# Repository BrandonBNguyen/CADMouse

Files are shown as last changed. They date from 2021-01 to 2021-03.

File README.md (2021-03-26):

# CAD Mouse Project

## Introduction

I took on this project because the middle mouse button on my mouse doesn't work well and if you're familiar with Solidworks and many other CAD software, the middle mouse button is often used to rotate, pan, and roll the model you are viewing. Manipulating the view of a CAD model without a functioning middle mouse button can be quite frustrating so I took on the task of developing a separate controller I could use specifically for performing these functions.

project showcase

## Part Selection

### Sensor Selection

I initially started by thinking about what sensors I would want to use to interpret commands to rotate, pan, roll, and zoom the view model. 

For the actions of rotating and panning the view model, I selected a simple joystick controller I had leftover from an Arduino kit because rotating and panning are actions that require both horizontal and vertical inputs from the mouse.

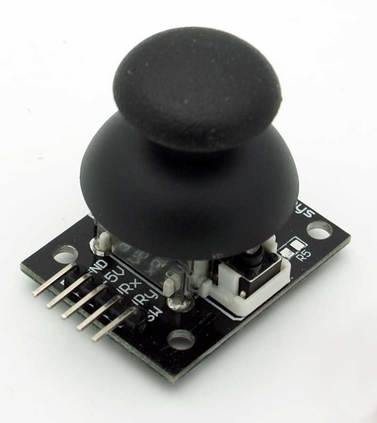
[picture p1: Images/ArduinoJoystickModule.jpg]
Arduino Joystick Module


For the actions of rolling and zooming the view model, I selected the KY-040 rotary encoder as these actions only require mouse movement along a single axis.

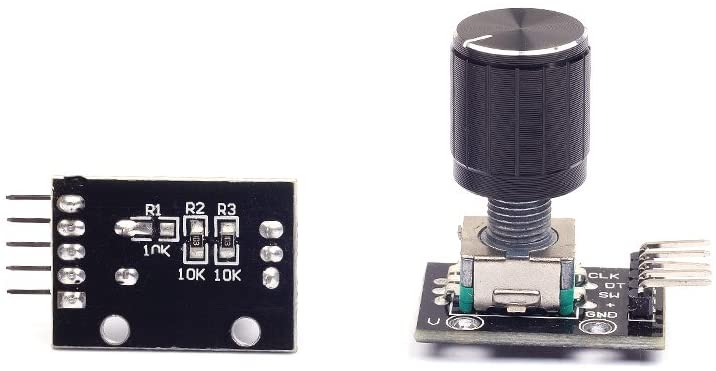
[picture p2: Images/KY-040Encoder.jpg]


### Board Selection

From preliminary testing with an Arduino Uno (which was unable to stimulate keyboard and mouse inputs to a computer), I knew I needed to select a microcontroller that would be able to appear as a native mouse and keyboard by implementing the `Mouse.h` and `Keyboard.h` libraries. As a result, I selected the Arduino Micro, which is a small Arduino board capable of implementing these libraries.

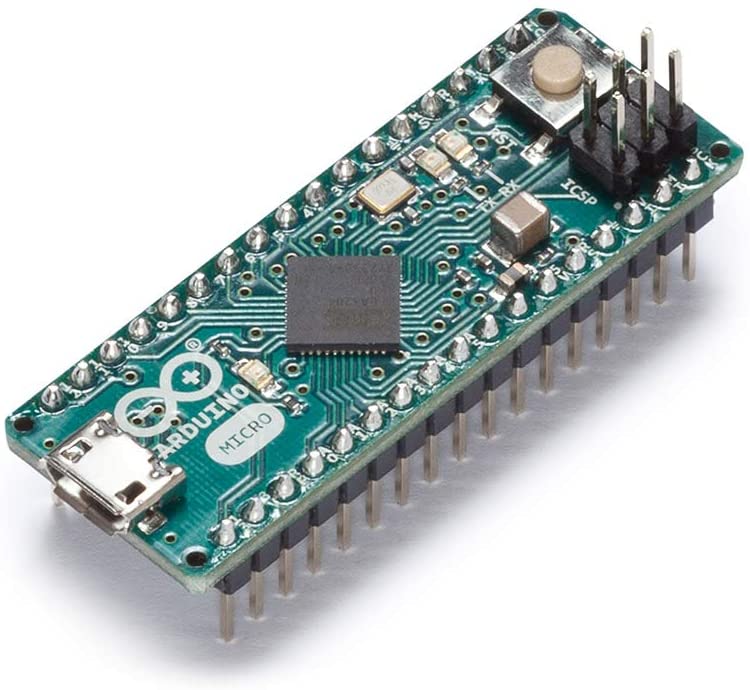
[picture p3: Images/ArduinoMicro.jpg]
Arduino Micro Microcontroller


## CAD Model

I started the design by importing existing CAD models of the electronic components into Solidworks and drawing  a rudimentary sketch of their placements relative to each other, being sure to take into account the clearances required of the Dupont wire connections to the sensor and board pins.

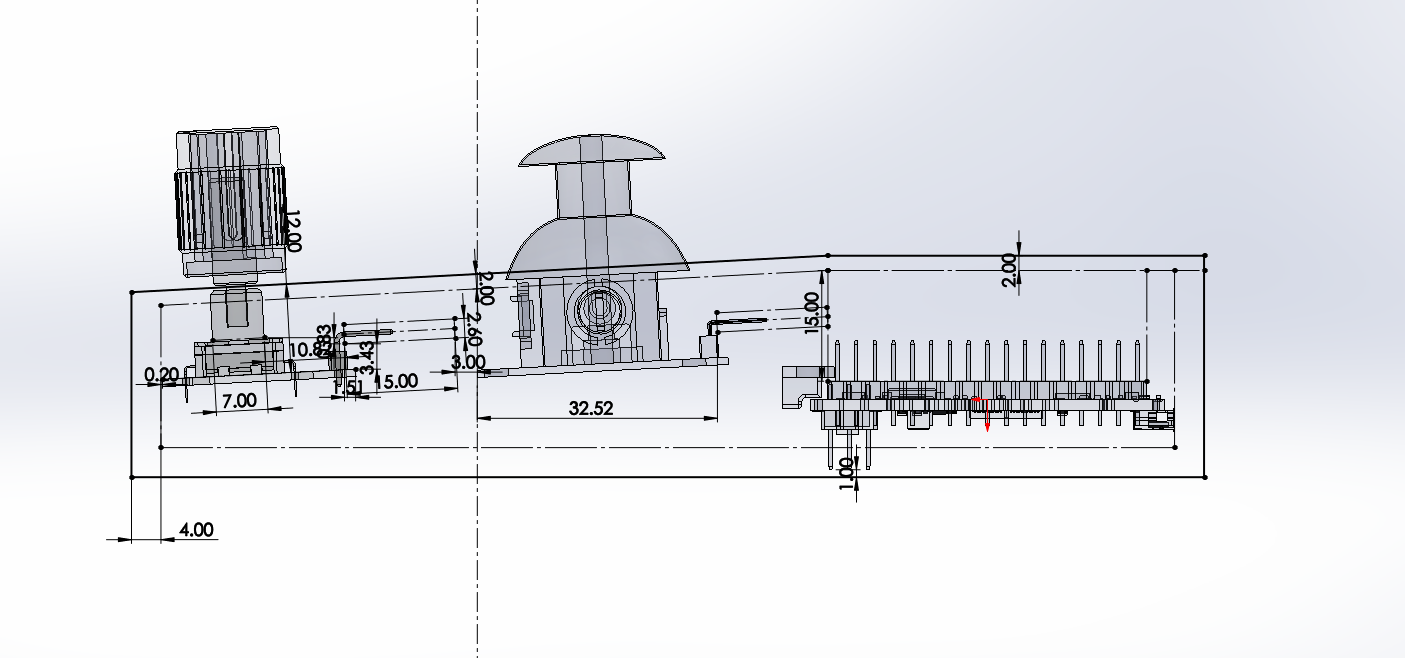
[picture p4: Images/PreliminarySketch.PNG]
Preliminary placement sketch


After fully defining and determining their placements, I modeled a case that would hold all the components in place via fasteners and provide an opening at the end for the micro USB port on the Arduino Micro. 

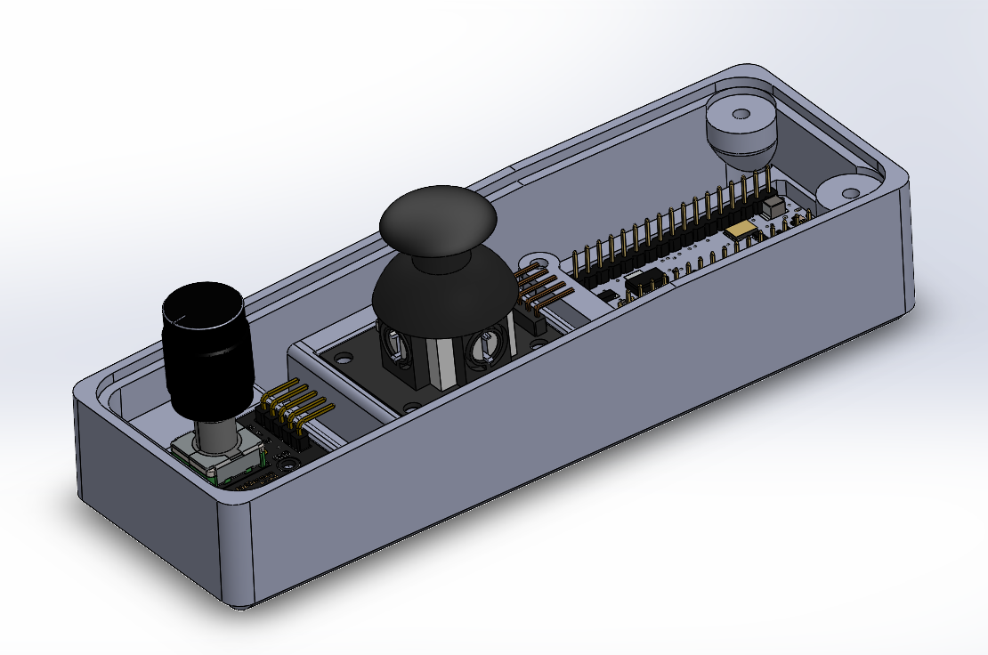
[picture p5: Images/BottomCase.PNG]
Case Model


After the case was designed, I modeled the lids that would be fastened to the case and enclose the wiring.

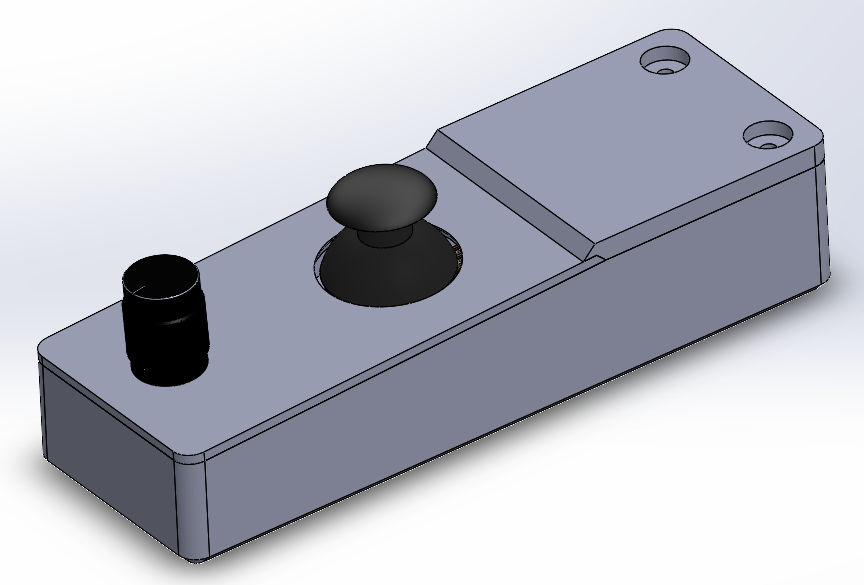
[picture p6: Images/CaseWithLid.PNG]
Enclosed Case Model


## Manufacturing

### 3D Printing

In order to prevent wasted plastic, I started by printing specifically the sections  of the case that interfaced with the electronic components to ensure proper fitting. By performing this step, I was able to find several instances where the components did not fit due to minor deviations between the CAD models of the components and their actual dimensions. Taking into account these differences, I was able to modify the CAD such that the components fit properly.

Below is a screenshot of the various iterations of the test prints used to ensure proper fitting of components to the case.

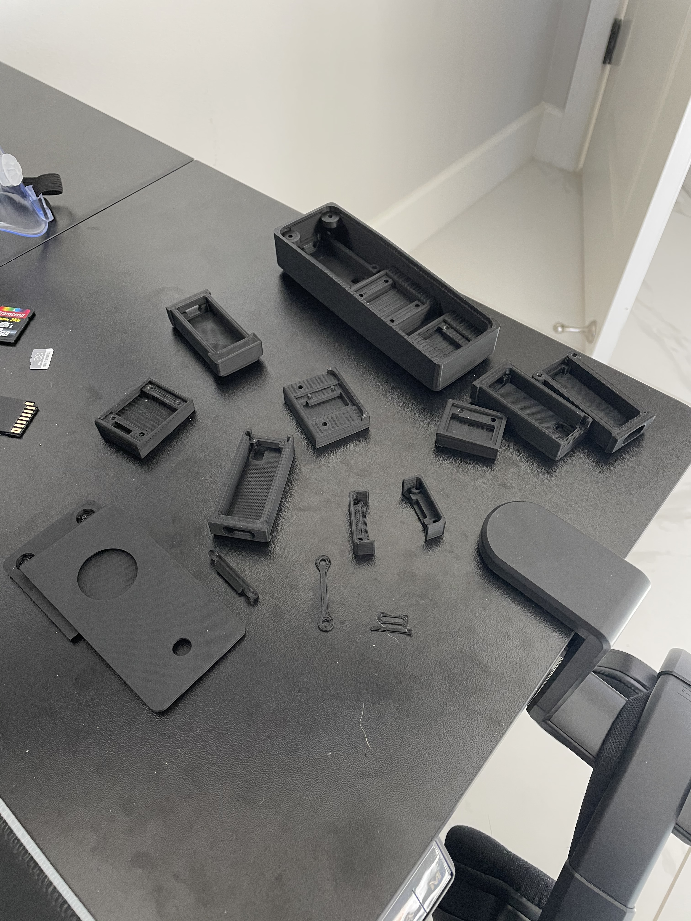
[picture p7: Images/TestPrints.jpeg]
Test Prints


### Wiring

The wiring between the sensors and the microcontroller was done using Dupont connectors. The connectors between the joystick and the Arduino Micro were shortened by cutting out segments of the connector, stripping the ends, soldering them together, and insulating them with electrical tape. 

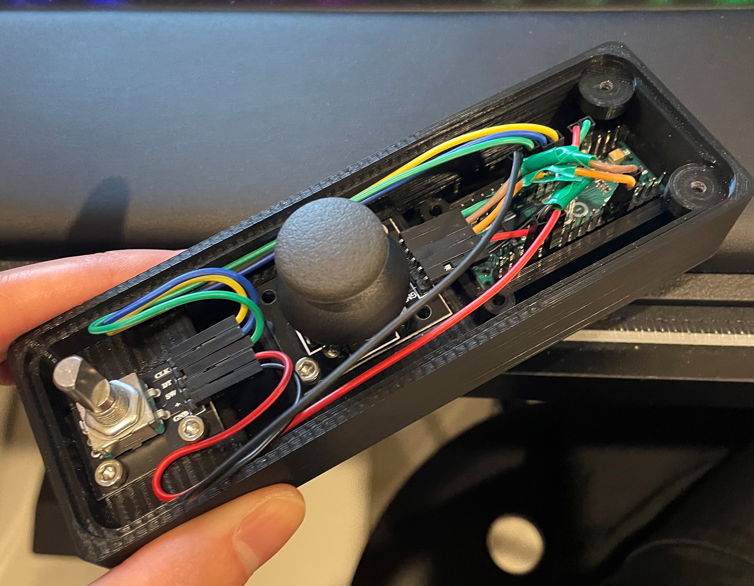
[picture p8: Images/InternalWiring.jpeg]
Internal Wiring


## User Guide

When the mouse is intially connected and booted up, the joystick controller is set such that moving it will cause the model to be rotated and the knob controller is set such that rotating it will cause the model to be rolled. 

Pressing down on the joystick and activating its switch will cause it to enter a panning mode such that inputs from the joystick cause the model to be panned instead of rotated. Pressing the joystick again will put it back in rotating mode.

Pressing down on the knob and activating its switch will cause it to enter a zooming mode such that inputs from the knob will cause the view window to zoom in and out of the model. Pressing the knob again will return the knob to rolling mode.

## Code Implementation

### Technical Challenges

The code run by the CAD Mouse is written and organized in `CAD_Mouse.ino`. The major technical problem I encountered while getting the mouse to manipulate the model smoothly was the mouse cursor colliding with the edge of the screen, preventing the view model from continuing to be moved in any way. The solution I came up with for this problem was to have the controller record the movements of the mouse from its initial position when the mouse was being used. During use, if the mouse cursor strayed too far from its initial position, the cursor would be quickly moved back to its initial position before continuing. This allowed the rotating and panning of view model to be fairly smooth when moving continuously.

### Organization

#### setup()

The initial `setup()` function is used to set up the input pins to read from the sensors and record the initial position of the rotary encoder.

#### loop()

The main `loop()`function reads data from the sensors and stimulates mouse and keyboard inputs to manipulate the CAD view. It performs the following tasks in sequence.

 1. Read the position of the joystick.
 2. Determine if the joystick switch has been pressed and switch between rotating and panning mode, accordingly.
 3. Determine if the knob switch has been pressed and switch between rolling and zooming mode, accordingly.
 4. If the joystick leaves the center position, begin stimulating mouse and keyboard inputs to move the CAD view model. If the joystick was already outside the center position, continue stimulating mouse movements to move the model. If the joystick reenters the center position, stop stimulating mouse and keyboard inputs.
 5. If the joystick isn't being used, read input from the rotary encoder. If the rotary encoder starts moving, begin stimulating mouse and keyboard inputs to move the model. Continue moving the model while rotary encoder  is still recording movement. If the rotary encoder has not recorded movement for a specified time, stop stimulating mouse and keyboard inputs.

Additionally, the code is factored in to several functions to help facilitate the tasks carried out by `loop()` and prevent repetitive code.

## Attributes

The links to the pre-made models used in the CAD made for this project are linked below.

 - [Arduino Micro](https://grabcad.com/library/arduino-micro-1) by Andrew Whitham
 - [HW-504 Joystick Module](https://grabcad.com/library/keyes-joystick-hw-504-1) by Barış Baylav
 - [KY-040 Rotary Encoder](https://grabcad.com/library/ky-040-rotary-encoder-1) by ∏-∑-A

## Skills Demonstrated

 - Demonstrated knowledge of C++ and applied it to use a microcontroller to read sensor data and control a system based on sensor inputs.
 - Demonstrated ability to write organized, well-commented code and write project documentation.
 - Demonstrated strong computer-aided design skills and good workflow by constraining existing components and developing custom parts around those in an assembly.
 - Demonstrated ability to perform rapid prototyping with the use of FDM 3D printing to test component fitting.

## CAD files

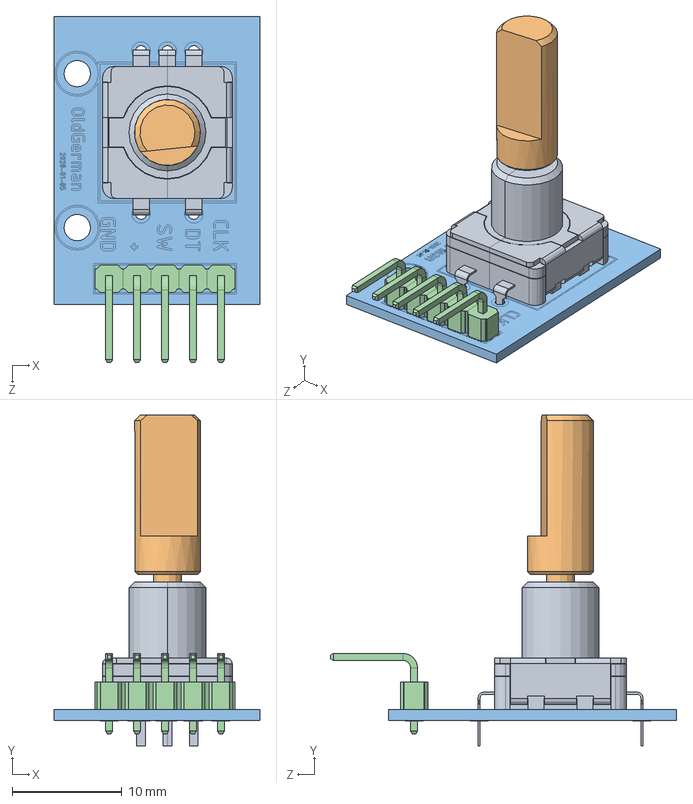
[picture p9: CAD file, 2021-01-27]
CAD/KY-040 Encoder/KY-040 Rotary Encoder.SLDASM
18.7 x 30.1 x 31.5 mm
Rotary Encoder
D-handle
pcb
2.54 5PIN 90

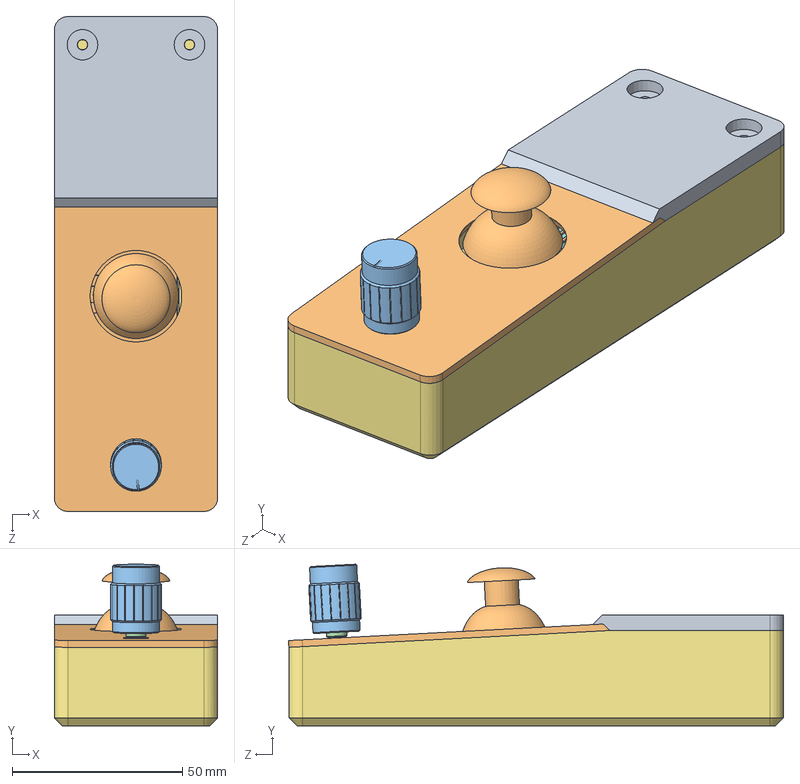
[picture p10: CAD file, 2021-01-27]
CAD/00 CAD Mouse.SLDASM
48.0 x 47.5 x 145.4 mm
arduinoMicro
Joystick HW504 Board
Rotary Encoder
D-handle
pcb
2.54 5PIN 90
Case Bottom
Arduino Micro Lid^CAD Mouse
Top Panel^CAD Mouse
Front Panel^CAD Mouse
Knob

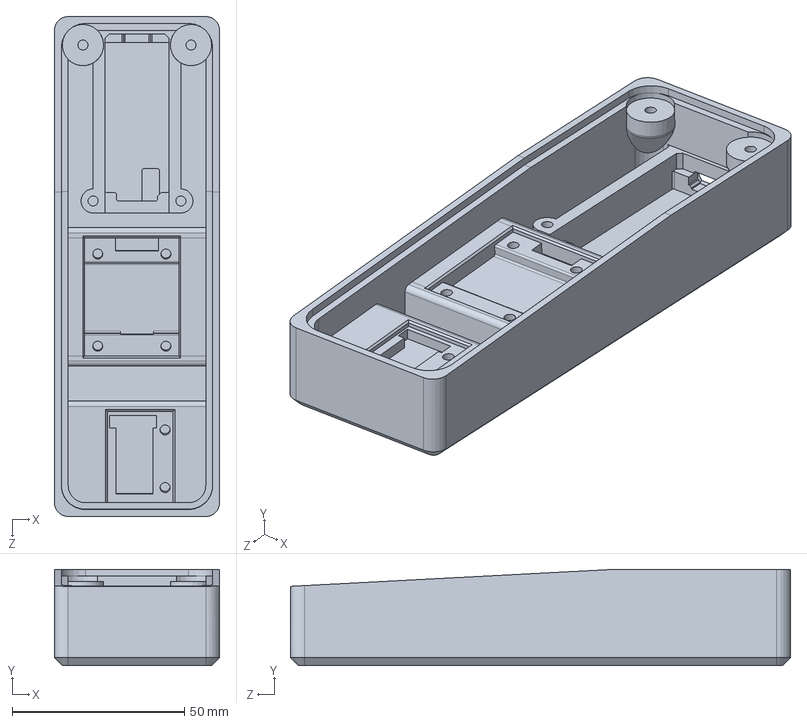
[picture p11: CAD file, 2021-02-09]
CAD/Case Bottom.SLDPRT
48.0 x 28.0 x 145.3 mm

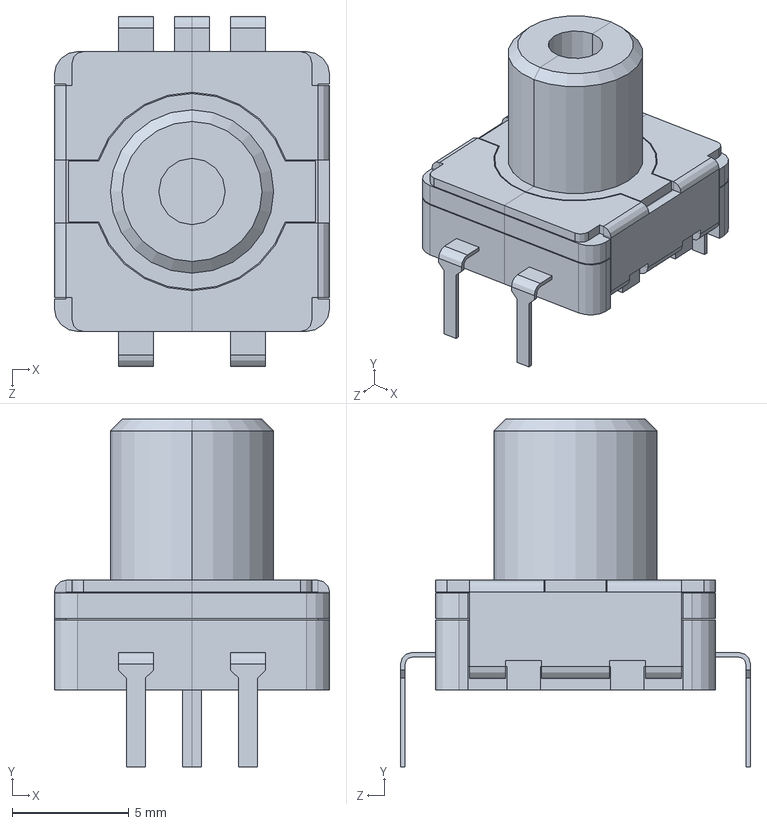
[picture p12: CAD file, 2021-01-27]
CAD/KY-040 Encoder/Rotary Encoder.SLDPRT
11.8 x 14.9 x 15.0 mm

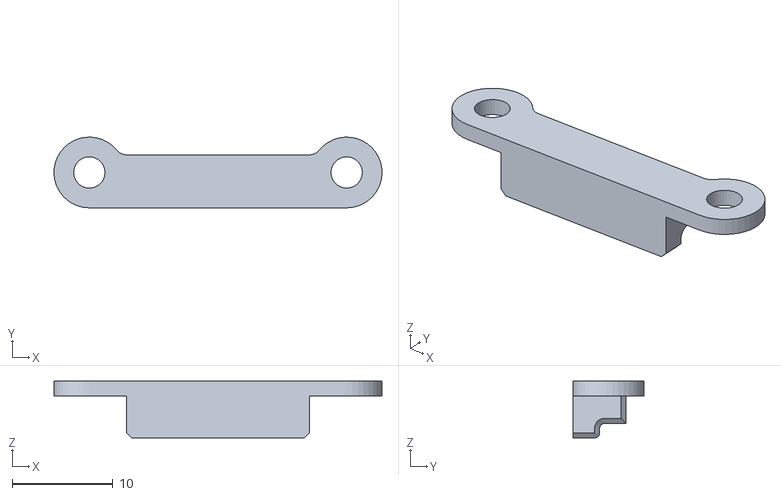
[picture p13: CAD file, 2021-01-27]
Print STL Files/Arduino Micro Lid.STL
32.5 x 7.02 x 5.65

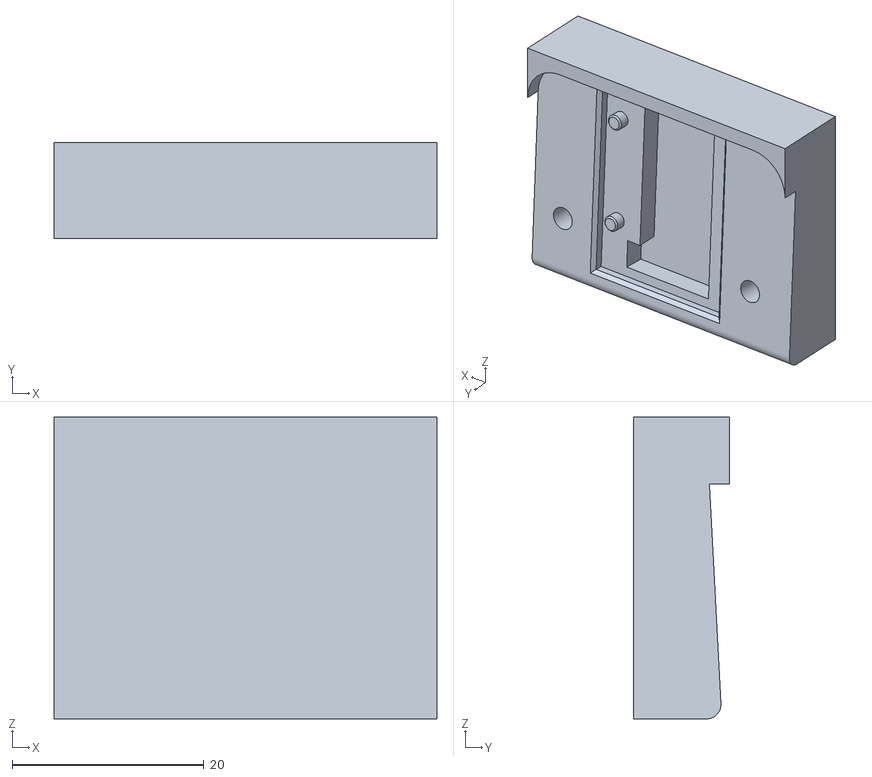
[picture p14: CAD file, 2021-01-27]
Test Prints/Rotary Encoder Holder (Holed).STL
40.0 x 10.0 x 31.5

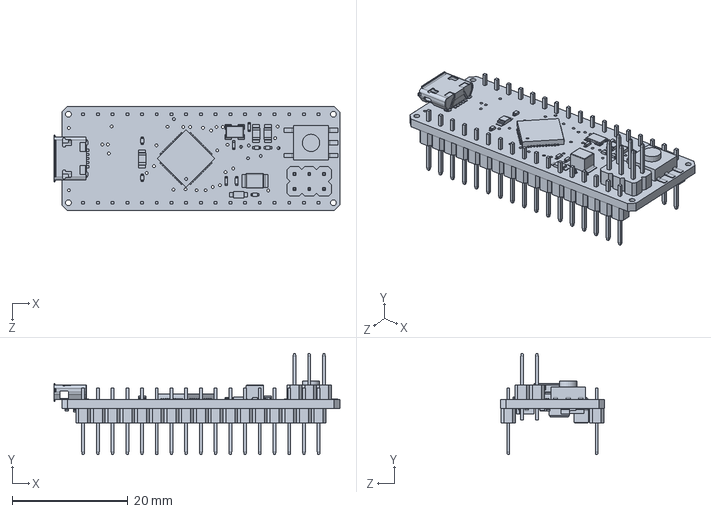
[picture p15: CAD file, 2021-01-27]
CAD/arduinoMicro.SLDPRT
49.4 x 17.5 x 18.0 mm

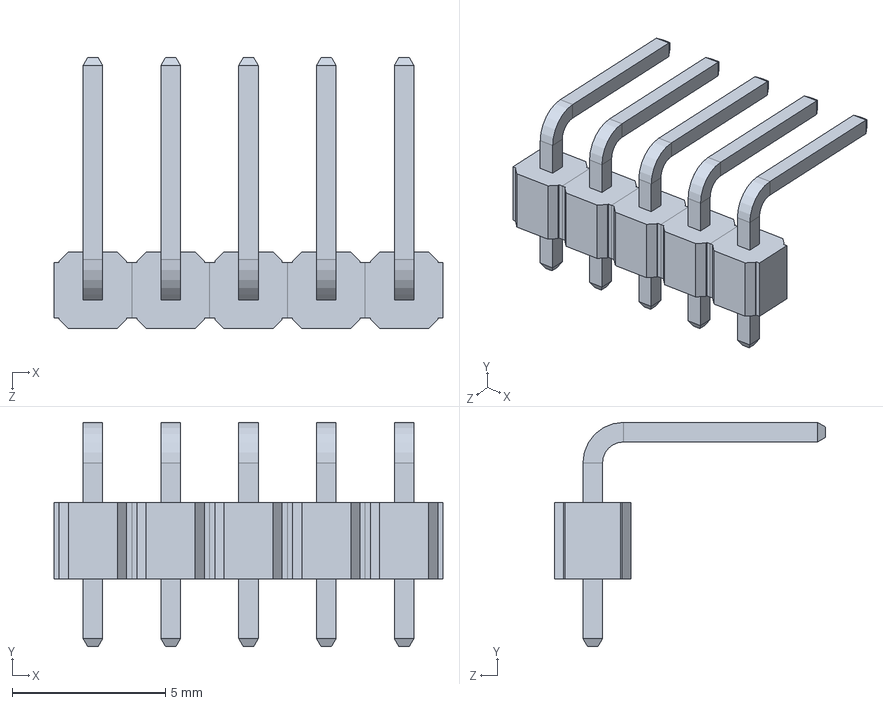
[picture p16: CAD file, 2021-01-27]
CAD/KY-040 Encoder/2.54 5PIN 90.SLDPRT
12.7 x 7.32 x 8.85 mm

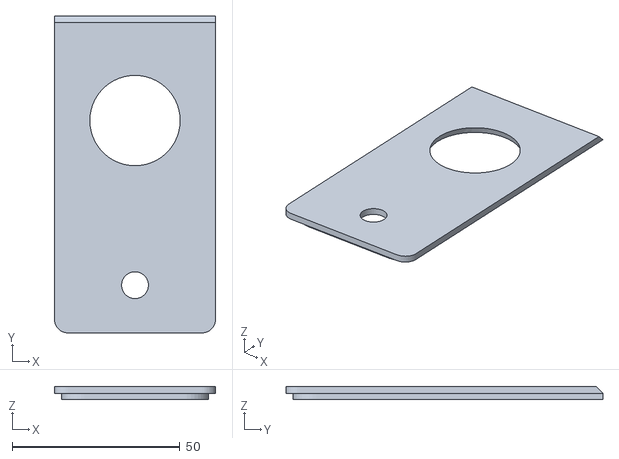
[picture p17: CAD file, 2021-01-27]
Print STL Files/Front Panel.STL
48.0 x 94.5 x 3.80

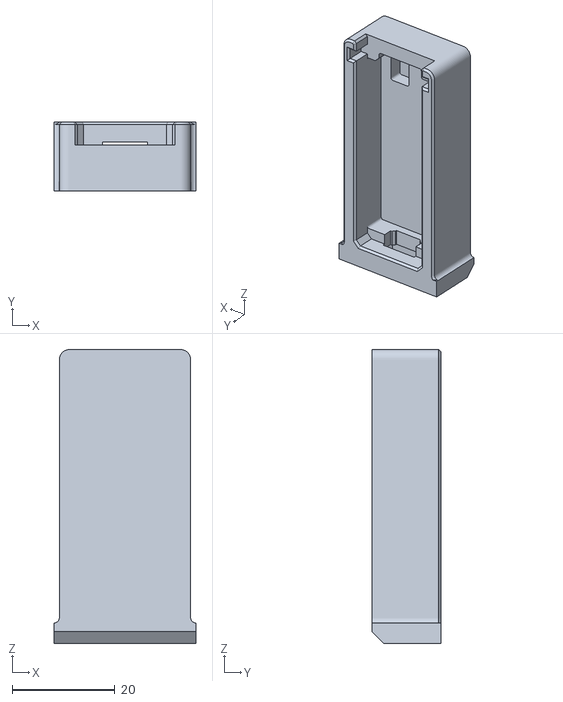
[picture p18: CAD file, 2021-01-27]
Test Prints/Arduino Micro Holder.STL
27.5 x 13.5 x 57.1

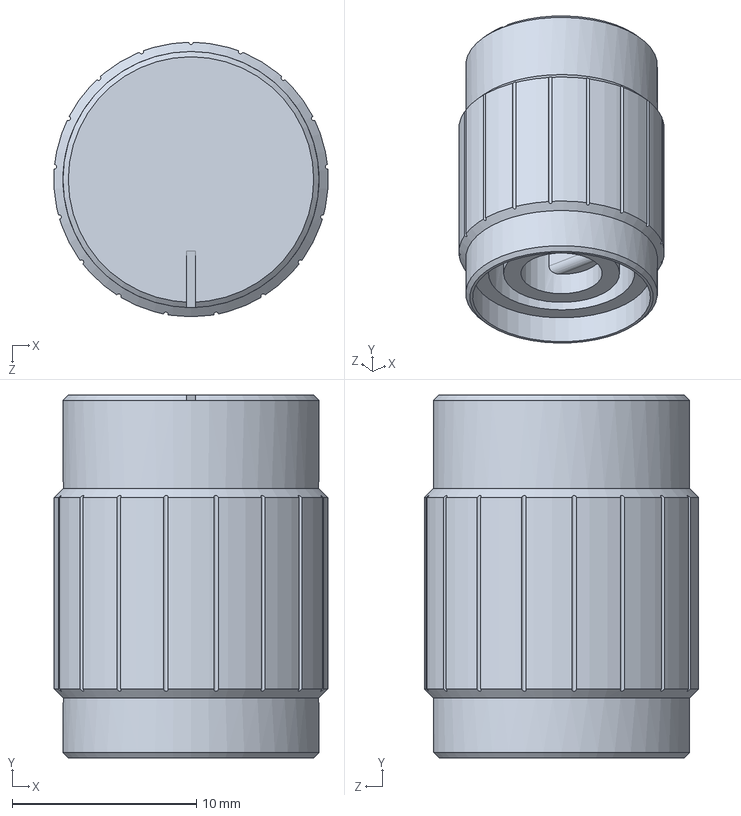
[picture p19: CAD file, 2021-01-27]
CAD/Knob.SLDPRT
14.9 x 19.7 x 14.9 mm

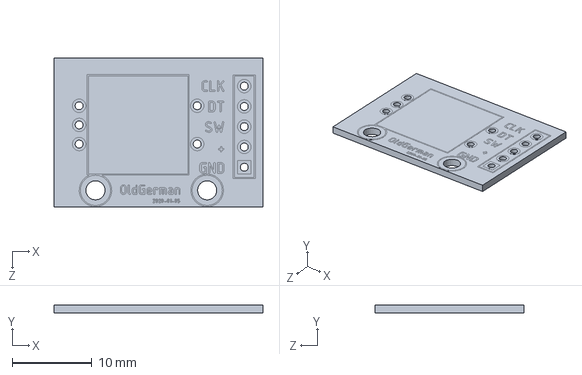
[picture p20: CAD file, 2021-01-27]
CAD/KY-040 Encoder/pcb.SLDPRT
26.2 x 1.02 x 18.7 mm

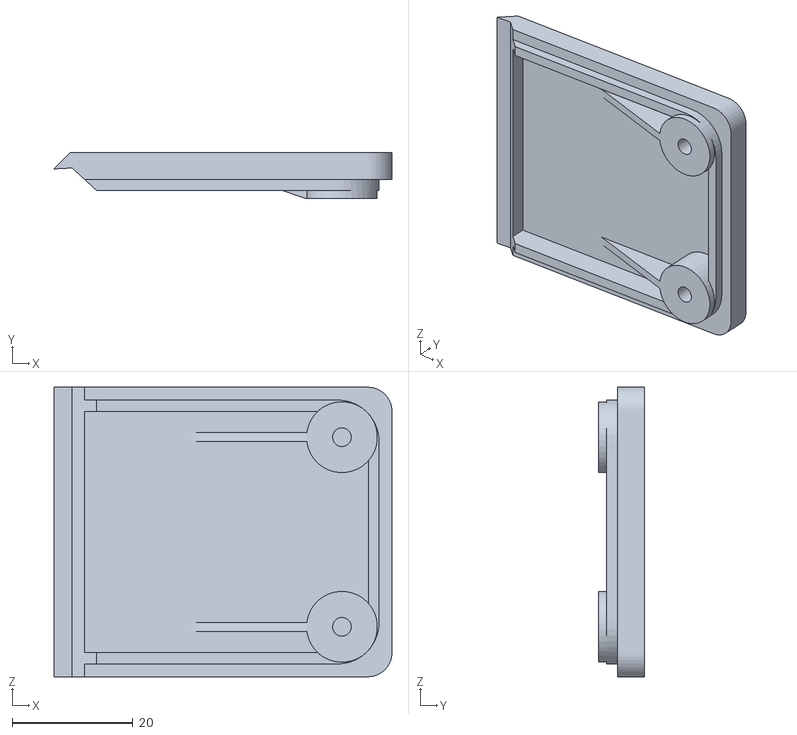
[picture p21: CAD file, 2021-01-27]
Print STL Files/Top Panel.STL
56.0 x 7.70 x 48.0

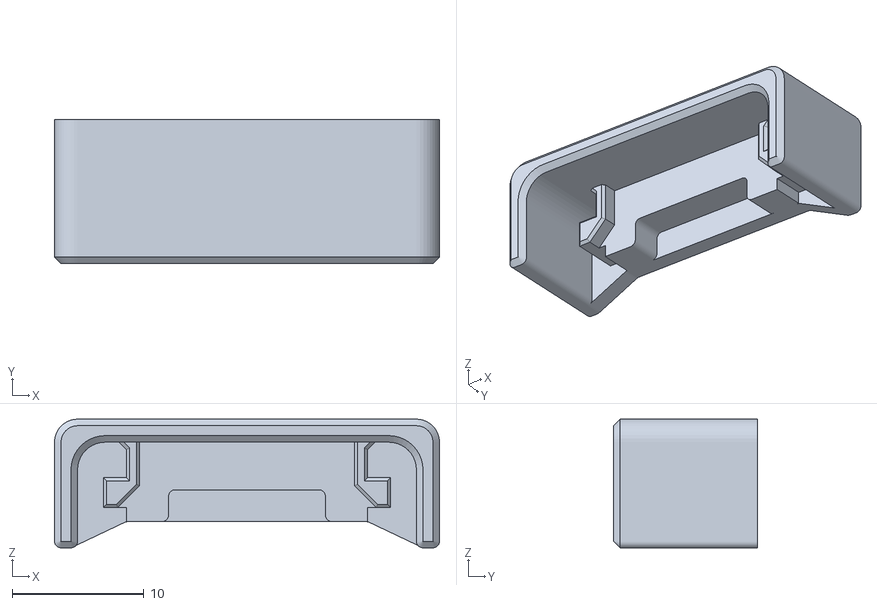
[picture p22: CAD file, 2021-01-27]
Test Prints/Arduino Micro Holder Lid.STL
29.2 x 11.0 x 9.77

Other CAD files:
CAD/Encoder KY-040.SLDPRT
CAD/KY-040 Encoder/D-handle.SLDPRT
Test Prints/Rotary Encoder Fix.STL
CAD/Joystick HW504 Board.SLDPRT
Print STL Files/Case Bottom.STL
Test Prints/Arduino Micro Holder (Holed).STL
Test Prints/Arduino Micro Holder Lid (Screwed).STL
Test Prints/Case Bottom Tester.SLDPRT
Test Prints/Joystick Tester.STL
Test Prints/Rotary Encoder Lid (Screwed).STL
Test Prints/Rotary Encoder Tester.STL

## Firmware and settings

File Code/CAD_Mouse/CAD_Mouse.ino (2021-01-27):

#include <Mouse.h>
#include <Keyboard.h>
#include <math.h>

// Pin Definitions
#define joy_VRy A1
#define joy_VRx A2
#define joy_switch 8
#define joy_5V 7

#define rotary_switch 3
#define rotary_DT 4
#define rotary_CLK 5

// Determine if the mouse and keyboard are being used.
int mouse_isAlive = false;
int keyboard_isAlive = false;

// Defines borders of region where mouse is allowed to be within
const int mouse_x_range = 3000; // Once mouse exits range of -1500 to 1500 in x, return the mouse to original position.
const int mouse_y_range = 900;  // Once mouse exits range of -450 to 450 in y, return the mouse to original position.

// Constants and variables regarding joystick control
const int   activationRadius         = 40;    // How far from the center does the switch need to be to actually activate MMB.
const float rotation_step_multiplier = 0.04;  // Governs mouse sensitivity for rotation. The higher, the faster the rotation.
const float panning_step_multiplier  = 0.04;  // Governs mouse sensitivity for panning. The higher, the faster the pan.
int         stick_x;                          // Variables for input from joystick sensor.
int         stick_y;
#define     DOWN                       0
#define     UP                         1
bool        joystick_pressed         = false; // Is true when the joystick switch is pressed and false when the joystick switch is released.
#define     ROTATING true                     // switch_threshold, then switch the joystick mode between rotating and panning.
#define     PANNING false
bool        joystick_mode = ROTATING;         // Joystick should initially be rotating the model.

// Constants and variables regarding rotary encoder control
const int   rolling_step_multiplier   = 15;    // Governs mouse sensitivity for rolling. The higher, the faster the roll.
const int   zoom_pulse_threshold      = 4;     // Governs the net number of pulses in the same direction required before initating mouse movement.
int         zoom_pulse_counter        = 0;
const int   rotary_off_threshold      = 35;
int         rotary_spin_off_counter   = 0;     // Counts the number of iterations since the last movement detected by the rotary encoder.
int         remaining_roll            = 0;     // Counts the amount of roll left to be executed.
int         prev_DT;                           // prev_DT and prev_CLK pins are used to determine the direction of rotation
int         prev_CLK;                          // when changes in the states of the DT and CLK pins are detected.
bool        rotary_pressed            = false; // Is true when the rotary switch is pressed and false when the rotary switch is released.
#define     ROLLING true                       // greater than switch_threshold, then switch the rotary encoder mode between rolling and
#define     ZOOMING false                      // zooming.
#define     CLOCKWISE -1
#define     COUNTERCLOCKWISE 1
bool        rotary_mode = ROLLING;             // Rotary encoder should initially be rolling the model.

// Mouse variables
int  mouse_pos_x = 0;     // Variables for tracking position of cursor relative to original position (measured in pixels).
int  mouse_pos_y = 0;
bool MMB_pressed = false; // Used to track if MMB is being held down during a movement (such as in rotating, panning, or rolling).

// Refresh Rate
const int refresh_rate = 144;

void setup() {
  pinMode(joy_switch, INPUT_PULLUP);
  pinMode(joy_5V, OUTPUT);
  digitalWrite(joy_5V, HIGH);
  
  pinMode(rotary_switch, INPUT_PULLUP);
  pinMode(rotary_DT, INPUT);
  pinMode(rotary_CLK, INPUT);

  prev_DT = digitalRead(rotary_DT);
  prev_CLK = digitalRead(rotary_CLK);
  #ifdef SerialDebugger
  Serial.begin(9600);
  #endif
}

bool outside_activationRadius(int stick_x, int stick_y) {
  // Returns whether the stick has been moved far enough to trigger mouse control.
  int center_x = stick_x - 511; // Coordinates with range of -511 to 512 with 0 being center.
  int center_y = stick_y - 511;
  #ifdef SerialDebugger
  Serial.println(sqrt(square(center_x) + square(center_y)));
  #endif
  if (sqrt(square(center_x) + square(center_y)) > activationRadius) {
    return true;
  } else {
    return false;
  }
}

void joystick_move_mouse(int stick_x, int stick_y) {
  // Move the mouse a certain amount depending on input from the joystick.
  float multiplier;
  if (joystick_mode == ROTATING) {
    multiplier = rotation_step_multiplier;
  } else {
    multiplier = panning_step_multiplier;
  }
  int move_x = floor(stick_x - 512) * 256 / 1024 * multiplier;  // Map the stick analog input (ranging from 0 to 1023) to signed
  int move_y = floor(stick_y - 512) * -256 / 1024 * multiplier; // char (ranging from -128 to 127) for use with Mouse.move().
  Mouse.move(move_x, move_y, 0);
  mouse_pos_x += move_x;
  mouse_pos_y += move_y;

  // If the mouse has exceeded the specified range, return the mouse.
  if (abs(mouse_pos_x) >= mouse_x_range / 2 || abs(mouse_pos_y) >= mouse_y_range / 2) {
    return_mouse();
  }
}

void return_mouse() {
  // Returns mouse to original position before usage.
  if (Mouse.isPressed(MOUSE_MIDDLE)) {
    Mouse.release(MOUSE_MIDDLE);
  }

  int move_x; // Break movement into largest chunks possible to achieve
  int move_y; // return movement in least amount of movements as possible.
  while (mouse_pos_x != 0 || mouse_pos_y != 0) {
    if (abs(mouse_pos_x) > 127) {
      if (mouse_pos_x > 0) {move_x = -127;}
      else {move_x = 127;}
    } else {
      move_x = -mouse_pos_x;
    }
    if (abs(mouse_pos_y) > 127) {
      if (mouse_pos_y > 0) {move_y = -127;}
      else {move_y = 127;}
    } else {
      move_y = -mouse_pos_y;
    }
    // Update mouse position while executing mouse movement.
    mouse_pos_x += move_x;
    mouse_pos_y += move_y;

    Mouse.move(move_x, move_y, 0);
  }
}

int get_rotary_movement() {
  // Returns the CLOCKWISE, COUNTERCLOCKWISE, or 0 depending on if there is rotation detected by the rotary encoder.
  int curr_DT = digitalRead(rotary_DT);
  int curr_CLK = digitalRead(rotary_CLK);
  
  int return_direction = 0;
  if (prev_DT != curr_DT) {
    if (prev_DT == HIGH) {
      if (prev_CLK == LOW) {
        return_direction = CLOCKWISE;
      } else {
        return_direction = COUNTERCLOCKWISE;
      }
    } else {
      if (prev_CLK == LOW) {
        return_direction = COUNTERCLOCKWISE;
      } else {
        return_direction = CLOCKWISE;
      }
    }
  } else if (prev_CLK != curr_CLK) {
    if (prev_CLK == HIGH) {
      if (prev_DT == LOW) {
        return_direction = COUNTERCLOCKWISE;
      } else {
        return_direction = CLOCKWISE;
      }
    } else {
      if (prev_DT == LOW) {
        return_direction = CLOCKWISE;
      } else {
        return_direction = COUNTERCLOCKWISE;
      }
    }
  }

  prev_DT = curr_DT;
  prev_CLK = curr_CLK;

  return return_direction;
}

void rotary_move_mouse() {
  // Move the mouse a certain amount depending on remaining roll required.
  int move_x;
  if (abs(remaining_roll) > 127) {
    if (remaining_roll > 0) {
      move_x = 127;
    } else {
      move_x = -127;
    }
  } else {
    move_x = remaining_roll;
  }
  mouse_pos_x += move_x;
  remaining_roll -= move_x;

  Mouse.move(move_x, 0, 0);

  // If the mouse has exceeded the specified range, return the mouse.
  if (abs(mouse_pos_x) >= mouse_x_range / 2 || abs(mouse_pos_y) >= mouse_y_range / 2) {
    return_mouse();
  }
}

void loop() {
  // Orient such that the +y direction is towards the output prongs and the +x direction is to the right of that.
  stick_x = 1023 - analogRead(joy_VRy);
  stick_y = 1023 - analogRead(joy_VRx);

  // Determine if the joystick switch has been triggered and switch mode between ROTATING or ROTATING, accordingly.
  int joy_switch_signal = digitalRead(joy_switch);
  if (joy_switch_signal == DOWN and !joystick_pressed) {
    #ifdef SerialDebugger
    Serial.println("JOYSTICK PRESSED");
    #endif
    joystick_pressed = true;
    if (joystick_mode == ROTATING) {
      joystick_mode = PANNING;
    } else {
      joystick_mode = ROTATING;
    }
  } else if (joy_switch_signal == UP and joystick_pressed) {
    #ifdef SerialDebugger
    Serial.println("JOYSTICK RELEASED");
    #endif
    joystick_pressed = false;
  }

  // Determine if the rotary encoder switch has been triggered and switch mode between ROLLING and ZOOMING, accordingly.
  int rotary_switch_signal = digitalRead(rotary_switch);
  if (rotary_switch_signal == DOWN and !rotary_pressed) {
    #ifdef SerialDebugger
    Serial.println("ROTARY PRESSED");
    #endif
    rotary_pressed = true;
    if (rotary_mode == ROLLING) {
      rotary_mode = ZOOMING;
    } else {
      rotary_mode = ROLLING;
    }
  } else if (rotary_switch_signal == UP and rotary_pressed) {
    #ifdef SerialDebugger
    Serial.println("ROTARY RELEASED");
    #endif
    rotary_pressed = false;
  }

  // When the stick initially leaves the activation radius, hold down the middle mouse button and move the cursor.
  if (!MMB_pressed && outside_activationRadius(stick_x, stick_y)) {
    if (joystick_mode == PANNING) {
      Keyboard.begin();
      keyboard_isAlive = true;
      #ifdef SerialDebugger
      Serial.println("JOYSTICK ACTIVATED KEYBOARD ONLINE");
      #endif
      Keyboard.press(KEY_LEFT_CTRL);
    }
    Mouse.begin();
    #ifdef SerialDebugger
    Serial.println("JOYSTICK ACTIVATED MOUSE ONLINE");
    #endif
    mouse_isAlive = true;
    if (!Mouse.isPressed(MOUSE_MIDDLE)) {
      Mouse.press(MOUSE_MIDDLE);
      #ifdef SerialDebugger
      Serial.println("JOYSTICK ACTIVATED MIDDLE CLICK");
      #endif
    }
    joystick_move_mouse(stick_x, stick_y);
    MMB_pressed = true;
  } else 

  // While the mouse continues to move outside the activation radius, continue moving the cursor.
  if (MMB_pressed && outside_activationRadius(stick_x, stick_y)) {
    joystick_move_mouse(stick_x, stick_y);

    // Since return_mouse() returns the mouse with the MMB unclicked, reclick it.
    if (!Mouse.isPressed(MOUSE_MIDDLE)) {
      Mouse.press(MOUSE_MIDDLE);
      #ifdef SerialDebugger
      Serial.println("RETURN MOUSE MIDDLE MOUSE CLICK");
      #endif
    }
  } else 

  // When the stick finally reenters the activation radius, release the middle mouse button and return the cursor to its original position.
  if (MMB_pressed && !outside_activationRadius(stick_x, stick_y)) {
    if (joystick_mode == PANNING) {
      Keyboard.release(KEY_LEFT_CTRL);
      Keyboard.end();
      #ifdef SerialDebugger
      Serial.println("JOYSTICK DEACTIVATED KEYBOARD OFFLINE");
      #endif
      keyboard_isAlive = false;
    }
    return_mouse();
    Mouse.end();
    #ifdef SerialDebugger
    Serial.println("JOYSTICK DEACTIVATED MOUSE OFFLINE");
    #endif
    mouse_isAlive = false;
    MMB_pressed = false;

    // Rotary Reset
    prev_DT = digitalRead(rotary_DT);
    prev_CLK = digitalRead(rotary_CLK);
    rotary_spin_off_counter = 0;
  } else {
    // If joystick is not being used to control the mouse, check and update rotary encoder stuff.
    int rotary_signal = get_rotary_movement();
    if (rotary_signal == 0 and remaining_roll == 0) {
      if (rotary_spin_off_counter <= rotary_off_threshold) {
        rotary_spin_off_counter++; // If there is no signal from the knob but it hasn't been long enough since the knob hasn't been touched,
      }                       // keep counting.
      if (rotary_spin_off_counter == rotary_off_threshold) {
        // If there is no signal from the knob and it has been long enough since the knob hasn't been touched, return the mouse and end
        // mouse and keyboard control.
        if (mouse_isAlive) {
          return_mouse();
          if (Mouse.isPressed(MOUSE_MIDDLE)) {
            Mouse.release(MOUSE_MIDDLE);
          }
          Mouse.end();
          mouse_isAlive = false;
        }
        if (keyboard_isAlive) {
          Keyboard.release(KEY_LEFT_ALT);
          Keyboard.end();
          keyboard_isAlive = false;
        }
      }
    } else {
      if (rotary_signal != 0) {
        // If input is being received from the knob, reset spin_off_counter and turn on control of mouse and keyboard to roll screen.
        Keyboard.begin();
        keyboard_isAlive = true;
        Keyboard.press(KEY_LEFT_ALT);
        Mouse.begin();
        mouse_isAlive = true;
        if (!Mouse.isPressed(MOUSE_MIDDLE)) {
          Mouse.press(MOUSE_MIDDLE);
        }
        rotary_spin_off_counter = 0;
      }
      if (rotary_mode == ROLLING) {
        // Roll mode
        // Add to existing remaining roll if there is input from the rotary. Otherwise, execute mouse movement to eliminate remaining roll.
        remaining_roll += rolling_step_multiplier * rotary_signal;
        rotary_move_mouse();
      } else {
        // Zoom mode
        // Count pulses from rotary. If pulses exceed threshold, scroll the mouse in the appropriate direction.
        zoom_pulse_counter += rotary_signal;
        if (abs(zoom_pulse_counter) >= zoom_pulse_threshold) {
          Mouse.move(0, 0, rotary_signal);
        }
      }
    }
  }

  delay((int)(1000 * 1 / refresh_rate)); // Execute loop at frequency specified by refresh_rate
}

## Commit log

2021-02-09 Organized CAD files into CAD folder
    [00 CAD Mouse.SLDASM, 2.54 5PIN 90.SLDPRT, Arduino Micro Lid.STL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]
2021-02-09 Code reorganization and renamed 'Tester Prints' to 'Test Prints'
    [Arduino Micro Holder (Holed).STL, Arduino Micro Holder Lid (Screwed).STL, Arduino Micro Holder Lid.STL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]
